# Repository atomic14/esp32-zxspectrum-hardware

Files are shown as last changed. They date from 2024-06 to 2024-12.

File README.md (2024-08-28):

# ESP32 S3 ZX Spectrum - Hardware

This repository contains the hardware design files for the ESP32 S3 ZX Spectrum project.

You can follow the progress of this project using the newsletter [here](https://esp32zx.substack.com/). Please subscibe to get updates on the project.

Newsletter (https://esp32zx.substack.com/)

## Schematic

Schematic

View the PDF version of the schematic [here](images/esp32-s3-spectrum.pdf).

## What does it look like?

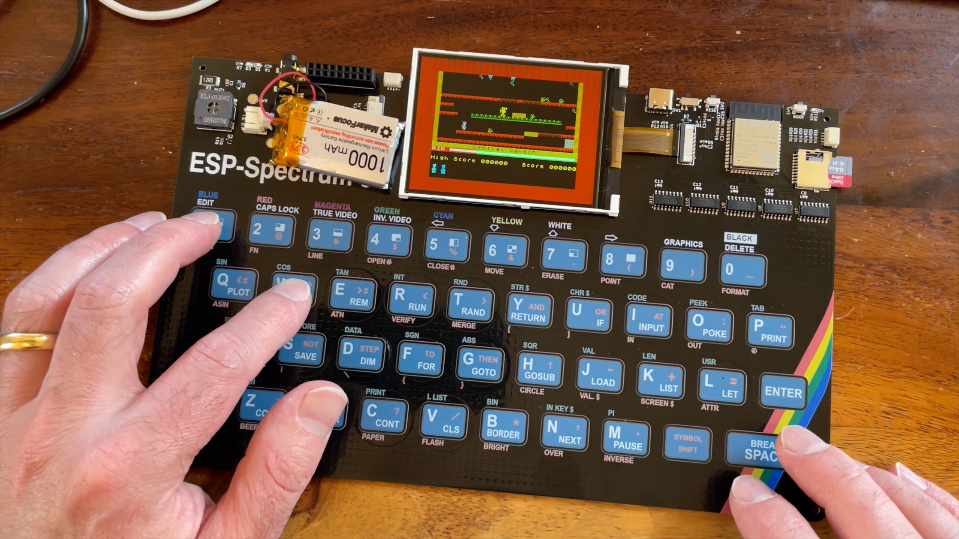
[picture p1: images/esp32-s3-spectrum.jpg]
ESP32 S3 ZX Spectrum (https://www.youtube.com/playlist?list=PL5vDt5AALlRf0H13krgzOf9XVX9lYcD5R)


## See it in action

There are a bunch of videos showing the project in action on my the [atomic14 YouTube channel](https://www.youtube.com/atomic14).

Click on the image to jump to the [playlist](https://www.youtube.com/playlist?list=PL5vDt5AALlRf0H13krgzOf9XVX9lYcD5R).

IMAGE ALT TEXT HERE (https://www.youtube.com/playlist?list=PL5vDt5AALlRf0H13krgzOf9XVX9lYcD5R)

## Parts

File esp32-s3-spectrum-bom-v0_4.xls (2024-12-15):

PCBWay Bom Quotation, Product No.:T-J142W267843A
Item # | *Designator | *Qty | Manufacturer | *Mfg Part # | Description / Value | *Package/Footprint | Mounting Type | Your Instructions / Notes | *Unit Price(5 sets) | *Total | *Delivery Time | *Actual Purchase Mfg Part # | Customer Reply | PCBWay Update
1 | C6, C7, C16, C18, C22 | 5 |  |  | 22uF | C_0603_1608Metric | SMD | Use generic part > 10V
2 | C8, C10, C11, C12, C13 | 5 |  |  | 100pF | C_0603_1608Metric | SMD | Use generic part > 10V
3 | C1, C4, C5, C15 | 4 |  |  | 2.2uF | C_0603_1608Metric | SMD | Use generic part > 10V
4 | C2, C3, C14, C20 | 4 |  |  | 1uF | C_0603_1608Metric | SMD | Use generic part > 10V
5 | C17, C19 | 2 |  |  | 0.1uF | C_0603_1608Metric | SMD | Use generic part > 10V
6 | C21 | 1 |  |  | 10uF | C_0603_1608Metric | SMD | Use generic part > 10V
7 | C23 | 1 |  |  | 470uF | CP_Elec_6.3x7.7 | SMD | Use generic part > 10V
8 | R28, R29, R30, R31, R32, R33 | 6 |  |  | 10K | R_0603_1608Metric | SMD | Use generic part > 10V
9 | R1, R2, R6, R7, R11 | 5 |  |  | 2.2K | R_0603_1608Metric | SMD | Use generic part > 10V
10 | R4, R10, R12 | 3 |  |  | 5.1K | R_0603_1608Metric | SMD | Use generic part > 10V
11 | R3 | 1 |  |  | 5R | R_2512_6332Metric | SMD | Use generic part > 2W
12 | R5 | 1 |  |  | 10R | R_0603_1608Metric | SMD | Use generic part > 10V
13 | R8 | 1 |  |  | 100R | R_0603_1608Metric | SMD | Use generic part > 10V
14 | R14 | 1 |  |  | 100K | R_0603_1608Metric | SMD | Use generic part > 10V
15 | L2 | 1 | FH | CBM160808U121T | CBM160808U121T | L0603 | SMD
16 | D2, D3 | 2 |  |  | GREEN | LED_0603_1608Metric | SMD | Use any geric GREEN LED
17 | D1 | 1 |  |  | RED | LED_0603_1608Metric | SMD | Use any generic RED LED
18 | D4 | 1 |  |  | BLUE | LED_0603_1608Metric | SMD | Use any generic BLUE LED
19 | D6 | 1 | MSKSEMI | 1N4007WS | 1N4007WS | D_SOD-323 | SMD
20 | U7, U8, U9, U10, U11 | 5 | Nexperia | 74HC4051D,653 | 74HC4051 | SOIC-16_3.9x9.9mm_P1.27mm | SMD
21 | U1 | 1 | TOPPOWER | TP4057-42-SOT26-R | TP4057 | SOT-23-6 | SMD
22 | U2 | 1 | Texas Instruments | TPS2117DRLR | TPS2117DRLR_C22399676 | SOT-583-8 | SMD
23 | U4 | 1 | Espressif Systems | ESP32-S3-WROOM-1-N8R8 | ESP32-S3-WROOM-1 | ESP32-S3-WROOM-1 | SMD
24 | U6 | 1 | onsemi | NCP167BMX330TBG | NCP167BMX330TBG | VREG_NCP167BMX330TBG | SMD
25 | U12 | 1 | STMicroelectronics | USBLC6-2P6 | USBLC6-2P6 | SOT-666 | SMD
26 | F1, F2 | 2 | JK | JK-SMD0603-200L | SMD0603-200L | F0603 | SMD
27 | SW2, SW4 | 2 | SHOU HAN | TS24CA | TS24CA | SW-SMD_TS24CA | SMD
28 | SW1 | 1 | G-Switch | MK-12C02-G020 | MK-12C02-G020 | SW-SMD_MK-12C02-G020 | SMD
29 | CN3, CN4 | 2 | Ckmtw | W-1251M02P-0400 | 1251SMT-2P_C132528 | CONN-SMD_1251SMT-2P | SMD
30 | QWIIC1, QWIIC2 | 2 | JST | SM04B-SRSS-TB(LF)(SN) | SM04B-SRSS-TB_LF__SN_ | JST_SM04B-SRSS-TB_LF__SN_ | SMD
31 | Card1 | 1 | 韩国韩荣 | SD-01A | SD-01A | SD-SMD_SD-01A | SMD
32 | CN1 | 1 | SHOU HAN | PJ-327A 5JJ | PJ-327A 5JJ | AUDIO-SMD_PJ-327A5JJ | SMD
33 | CN2 | 1 | Kinghelm | KH-CL0.5-H2.0-18PIN | KH-CL0.5-H2.0-18PIN | FPC-SMD_KH-CL0.5-H2.0-18PIN | SMD
34 | Q2 | 1 | TECH PUBLIC | TPNTA4153NT1G | TPNTA4153NT1G | SOT-523 | SMD
35 | J1 | 1 | 韩国韩荣 | TYPE-C-31-M-12 | TYPE-C-31-M-12 | HRO_TYPE-C-31-M-12 | SMD
 |  |  |  |  |  |  |  |  | Component Cost
 |  |  |  |  |  |  |  |  | Assembly Cost
 |  |  |  |  |  |  |  |  | PCB Cost
 |  |  |  |  |  |  |  |  | V3 Member 3% off
 |  |  |  |  |  |  |  |  | All Total 5 Sets

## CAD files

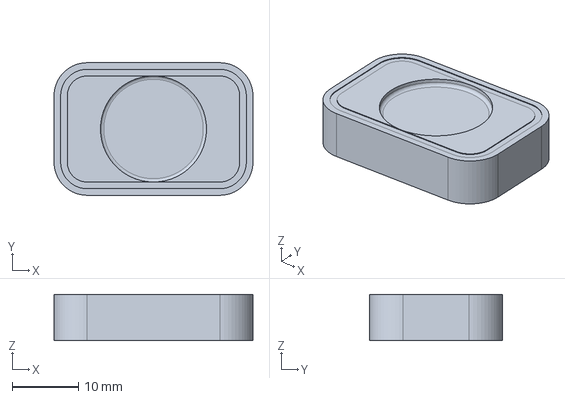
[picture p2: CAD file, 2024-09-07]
3dmodels/speaker.step
30.0 x 20.0 x 7.00 mm

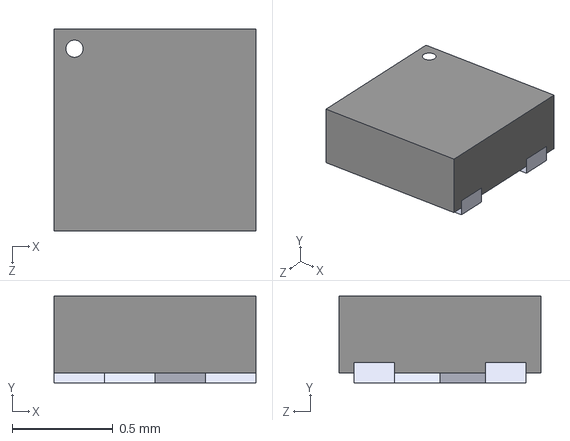
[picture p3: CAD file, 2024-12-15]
NCP167BMX330TBG/NCP167BMX330TBG.step
1.00 x 0.43 x 1.00 mm

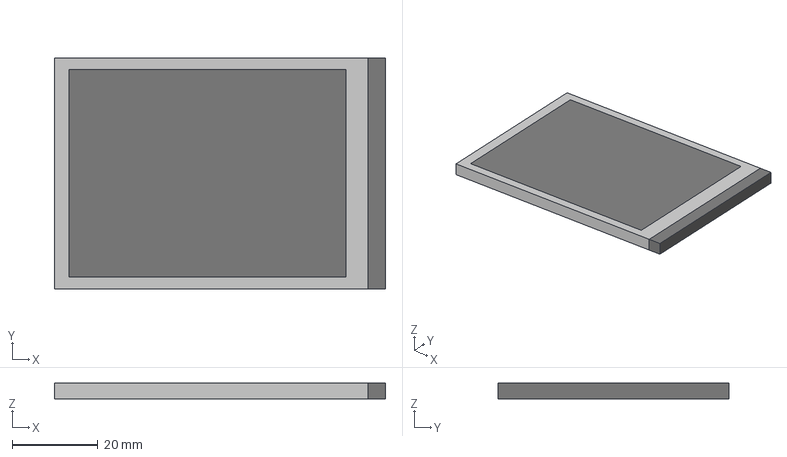
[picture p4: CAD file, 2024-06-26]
3dmodels/screen-screen v004.step
77.4 x 54.0 x 3.70 mm
screen v1
screen v002
screen v003

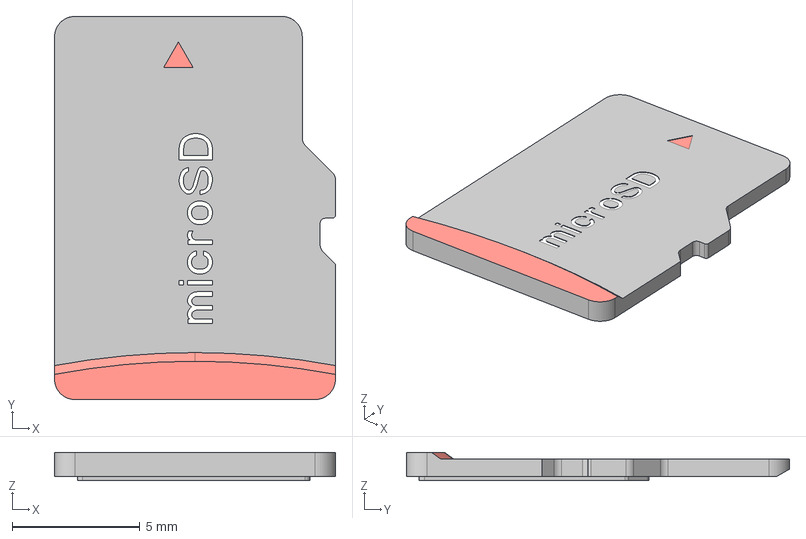
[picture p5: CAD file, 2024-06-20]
3dmodels/microsd-card.stp
11.0 x 15.0 x 1.10 mm

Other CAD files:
3dmodels/screen.step
3dmodels/screen.FCStd

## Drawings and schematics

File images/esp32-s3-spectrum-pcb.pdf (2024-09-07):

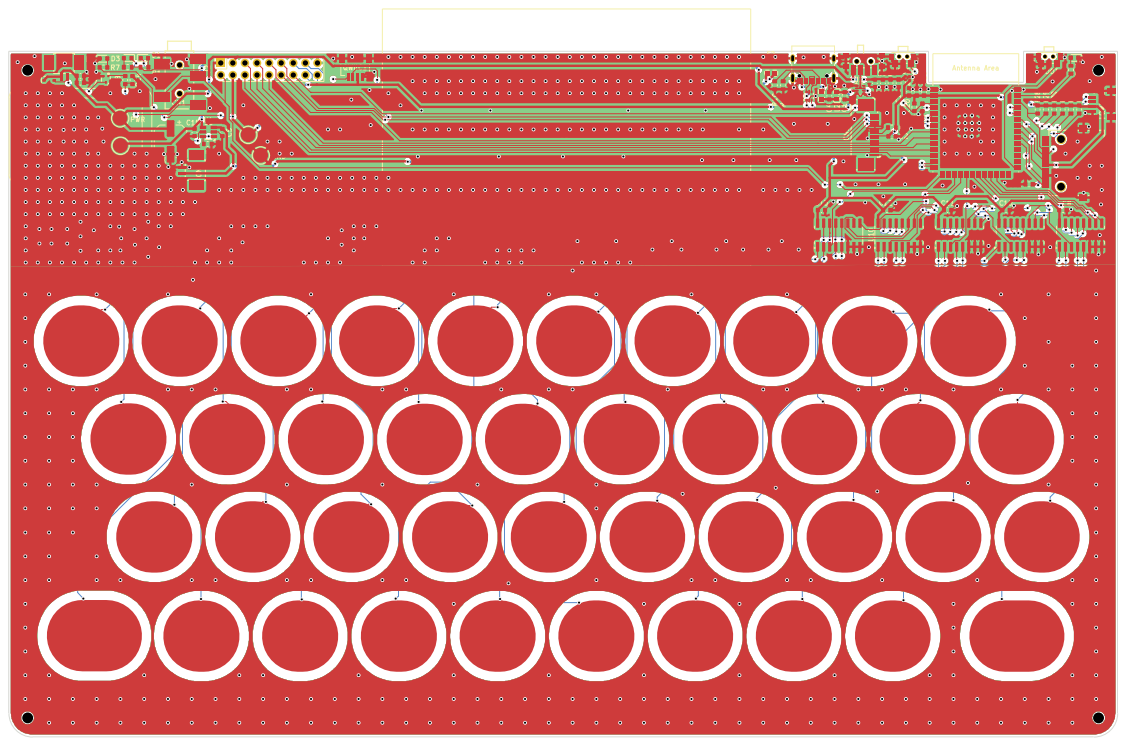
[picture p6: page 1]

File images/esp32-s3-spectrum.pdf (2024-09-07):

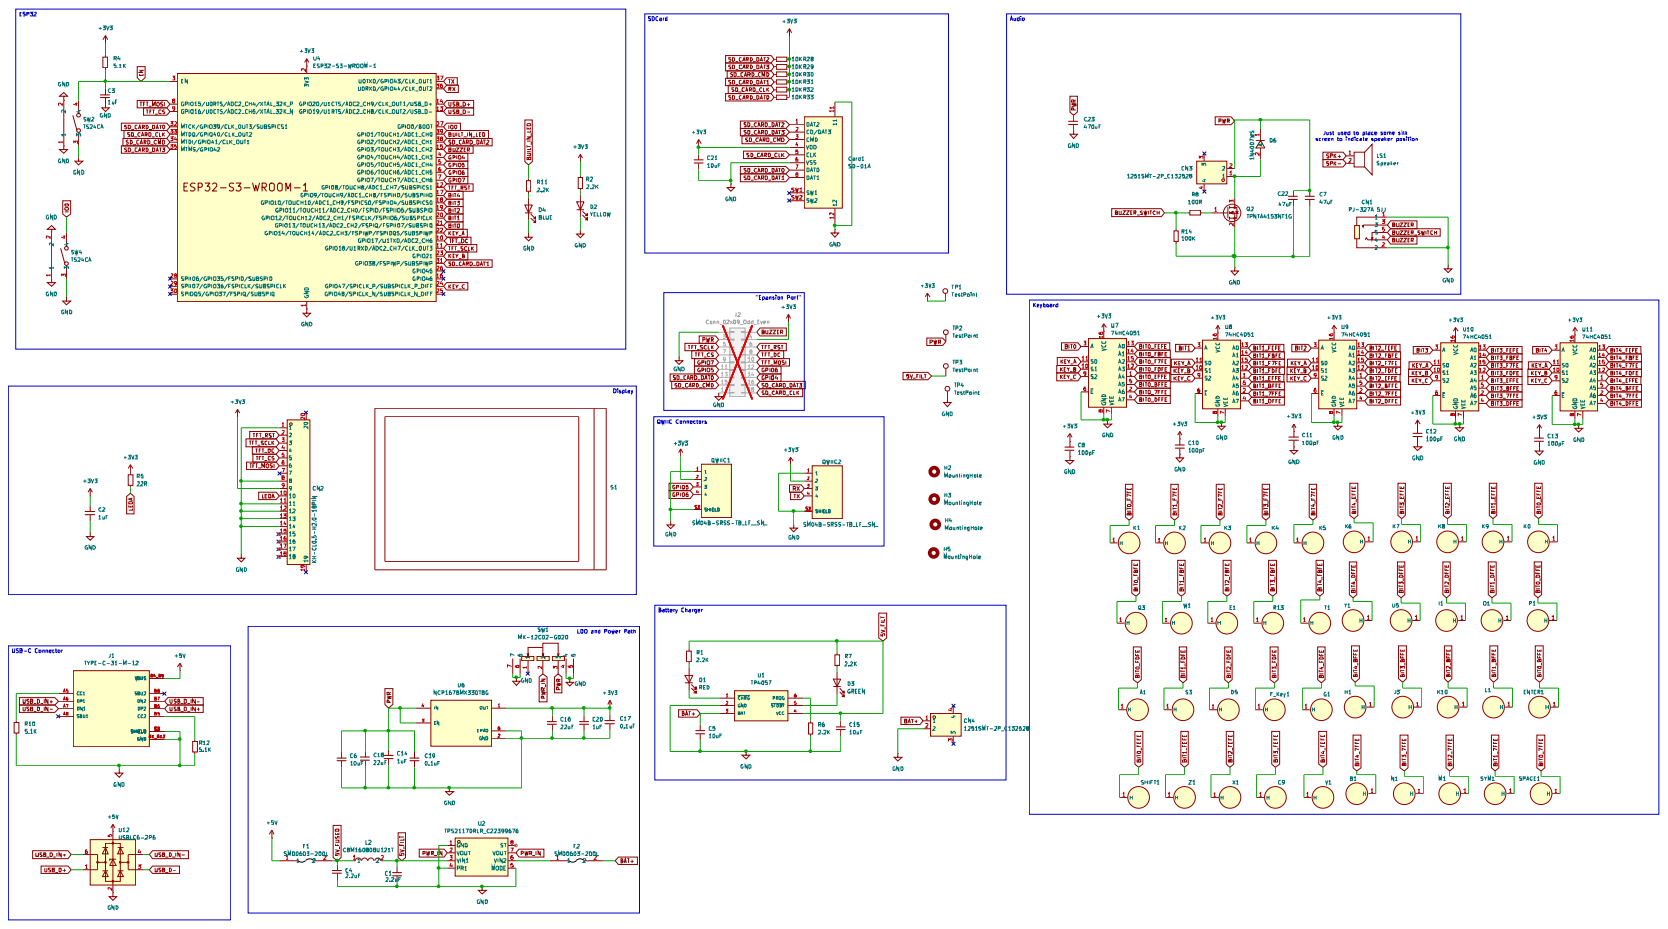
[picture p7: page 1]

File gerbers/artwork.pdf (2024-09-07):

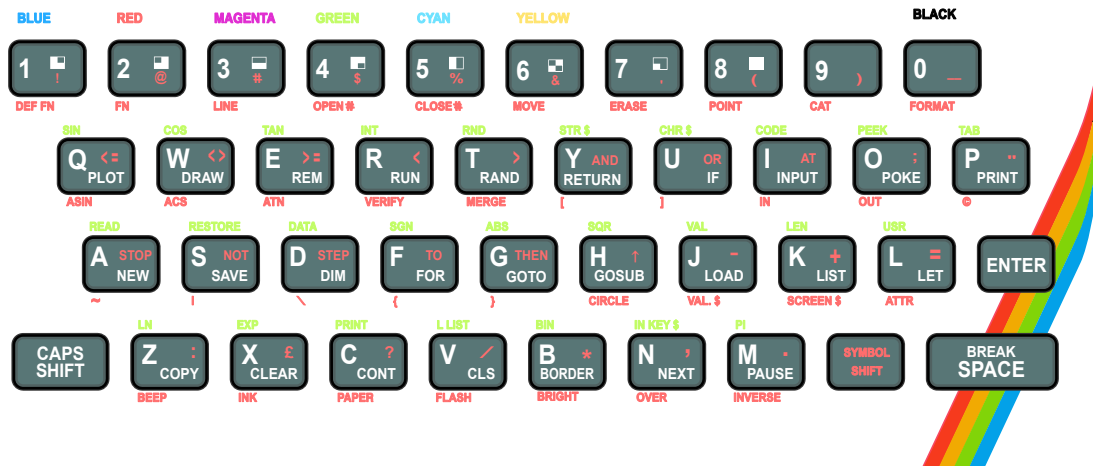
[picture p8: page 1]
BLACK; EDIT; CAPS LOCK; TRUE VIDEO; INV. VIDEO; BLUE; RED; MAGENTA; GREEN; CYAN; YELLOW; WHITE; GRAPHICS; DELETE; SIN; COS; TAN; INT; RND; STR $; CHR $; CODE; PEEK; TAB; READ; RESTORE; DATA; SGN; ABS; SQR; VAL; LEN; USR; EXP; PRINT; L LIST; BIN; IN KEY $; DEF FN; LINE; OPEN #; CLOSE #; MOVE; ERASE; POINT; CAT; FORMAT; ASIN; ACS; ATN; VERIFY; MERGE; OUT; BEEP; INK; PAPER; FLASH; BRIGHT; OVER; INVERSE; CIRCLE; VAL. $; SCREEN $; ATTR; SYMBOL; SHIFT; CAPS SHIFT; ENTER; BREAK; COPY; CLEAR; CONT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

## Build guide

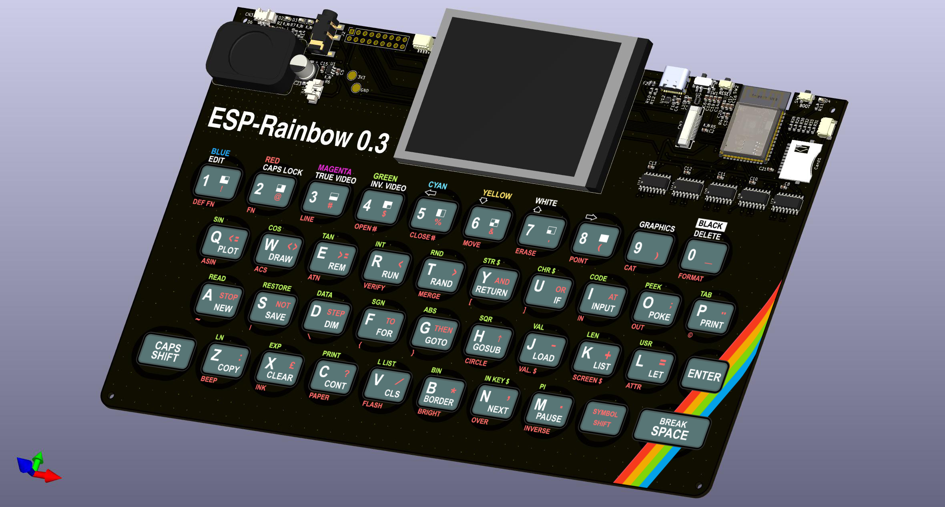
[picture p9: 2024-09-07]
gerbers/artwork-instructions.jpg

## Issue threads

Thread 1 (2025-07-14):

3D printed case

andypiper, 2025-07-14:
Has anyone printed a case or holder for the esp32rainbow yet? wondering whether anyone has anything to share :-)

cgreening, 2025-07-14:
I haven't seen anything yet - my 3D printer is actually too small to print something big enough :(

Closed 2025-07-19.

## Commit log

2024-06-02 Version 1.0
    [esp32-s3-spectrum-B_Cu.gbr, esp32-s3-spectrum-B_Mask.gbr, esp32-s3-spectrum-B_Paste.gbr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]
2024-06-02 Fixes speaker driver and USB connection
    [esp32-s3-spectrum.kicad_pcb, esp32-s3-spectrum.kicad_sch]
2024-06-06 Add back battery charging
    [esp32-s3-spectrum.kicad_pcb, esp32-s3-spectrum.kicad_sch]
2024-06-11 Additional silk screen
    [esp32-s3-spectrum.kicad_pcb, esp32-s3-spectrum.kicad_sch]
2024-06-20 New Keyboard
    [esp32-s3-spectrum.kicad_pcb, esp32-s3-spectrum.kicad_sch, microsd-card.stp]
2024-06-26 Almost ready to submit
    [esp32-s3-spectrum.kicad_pcb, esp32-s3-spectrum.kicad_sch, screen-screen v004.step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]
2024-06-26 New expansion header
    [esp32-s3-spectrum.kicad_pcb, esp32-s3-spectrum.kicad_sch]
2024-06-27 Version 0.1 submitted
    [esp32-s3-spectrum-B_Cu.gbr, esp32-s3-spectrum-B_Mask.gbr, esp32-s3-spectrum-B_Paste.gbr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]
2024-06-28 Final submission with quoted bom
    [QuotedBOM.xls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]
2024-08-10 Fix SD Card on expansion port
    [esp32-s3-spectrum.kicad_pcb, esp32-s3-spectrum.kicad_sch]
2024-08-26 Version 0.2 new artwork and 4 layer board
    [esp32-s3-spectrum.kicad_pcb, esp32-s3-spectrum.kicad_sch]
2024-08-28 Fixing up BOM
    [QuotedBOM.xls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]
2024-09-07 More tweaks
    [esp32-s3-spectrum.kicad_pcb, esp32-s3-spectrum.kicad_sch, speaker.step]
2024-09-07 Ready to submit
    [esp32-s3-spectrum-B_Cu.gbr, esp32-s3-spectrum-B_Mask.gbr, esp32-s3-spectrum-B_Paste.gbr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]
2024-09-07 Reduced number of vias to reduce cost
    [esp32-s3-spectrum-B_Cu.gbr, esp32-s3-spectrum-B_Mask.gbr, esp32-s3-spectrum-B_Paste.gbr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]
2024-09-07 Adds complete BOM
    [esp32-s3-spectrum-bom-v0_3.xls]
2024-09-07 Fix missing vias
    [esp32-s3-spectrum.kicad_pcb]
2024-09-07 Final final submission to PCBWay...
    [esp32-s3-spectrum-B_Cu.gbr, esp32-s3-spectrum-B_Mask.gbr, esp32-s3-spectrum-B_Paste.gbr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]
2024-12-15 Version 0.4
    [NCP167BMX330TBG.step, QuotedBOM.xls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]
